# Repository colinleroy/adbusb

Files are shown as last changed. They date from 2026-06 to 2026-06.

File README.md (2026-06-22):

#  ADB to USB converter for Apple keyboards

Allow one ADB keyboard to be used on one ADB computer (old Macintosh and Apple IIgs) and one USB computer at the same time by switching between them.

Illustration

## What works

- adb passthrough between a macintosh and keyboard/mouse + softpower
- adb keyboard to usb-hid conversion:
  - iso and ansi layouts
  - locking caps lock
  - power key in usb (translated as 0x66 "keyboard power")
- tested on multiple keyboards: aek ii, m0116/m0118, appledesign...
- tested on macintosh se
  
## What don't work yet

- keyboard leds on usb: the *keyboard* library doesn't handle hid output reports
- hotplugging adb: works randomly, the microcontroller don't seems to like that
- mouse passthrough in usb-hid mode
- correct keyboard detection by the macintosh when the board is in usb mode: not a problem in practice
- collision detection handling: the program calls the keyboard at address 2

## Hardware needed

- arduino pro micro because it works on 5V and is hid capable
- a resistor (1K - 10K ohm) for the pull up
- 2 mini-din 4 pin connectors
- 2-pin switch

## How to build it

- connect the switch between A3 (PF4) and GND
- connect GND on the two mini-din pins 4
- connect 9 (PB5) to the mini-din A pin 1 (computer adb line)
- connect 8 (PB4) to the mini-din A pin 2 (computer softpower line)
- connect VCC to the mini-din B pin 3 (keyboard power)
- connect 10 (PB6) to VCC through the resistor
- connect 10 (PB6) to the mini-din B pin 1 (keyboard adb line)
- connect 16 (PB2) to the mini-din B pin 2 (keyboard softpower line)
- mark the mini-din B as the keyboard connector

> [!CAUTION]
> i don't know what happens if you invert the connectors and inject external 5V into the macintosh adb

Mini-DIN female connector front view :
```
/------\
| 4  3 |
| 2  1 |
\__==__/
```

Arduino Pro Micro pinout :
```
                                ___________
                     PD3  TXD  |    USB    |  RAW
                     PD2   20  |           |  GND        --- keyboard pin 4
                          GND  |           |  RST
computer pin 4 ---        GND  |           |  VCC        --- keyboard pin 3 ---
                     PD1    2  |           |  A3   PF4                         |
                     PD0    3  |           |  A2   PF5                         _
                     PD4    4  |           |  A1   PF6                        | |
                     PC6    5  |           |  A0   PF7               resistor | |
                     PD7    6  |           |  15   PB1                        |_|
                     PE6    7  |           |  14   PB3                         |
computer pin 2 ---   PB4    8  |           |  16   PB2   --- keyboard pin 2    |
computer pin 1 ---   PB5    9  |___________|  10   PB6   --- keyboard pin 1 ---

```

## How to compile and upload it

1. install `arduino-cli`
2. `arduino-cli core install arduino:avr`
3. `arduino-cli lib install Keyboard`
4. compile this project by `cd` in then `arduino-cli compile --fqbn arduino:avr:micro`
5. connect the board to the computer
6. get board port with `arduino-cli board list`
7. upload it `arduino-cli upload -p /dev/.......`

## References

- [Guide to the Macintosh family hardware, Chapter 8 : Apple Desktop Bus, Apple, 1990](https://archive.org/details/apple-guide-macintosh-family-hardware/page/n325/mode/2up)
- [Apple Desktop Bus Protocol, lopaciuk.eu, 2021](https://www.lopaciuk.eu/2021/03/26/apple-adb-protocol.html)
- [Understanding the ADB Service Request Signal, bigmessowires, 2016](https://www.bigmessowires.com/2016/03/30/understanding-the-adb-service-request-signal/)
- [Apple Desktop Bus (ADB), wiki.preterhuman.net](https://wiki.preterhuman.net/Apple_Desktop_Bus_(ADB))

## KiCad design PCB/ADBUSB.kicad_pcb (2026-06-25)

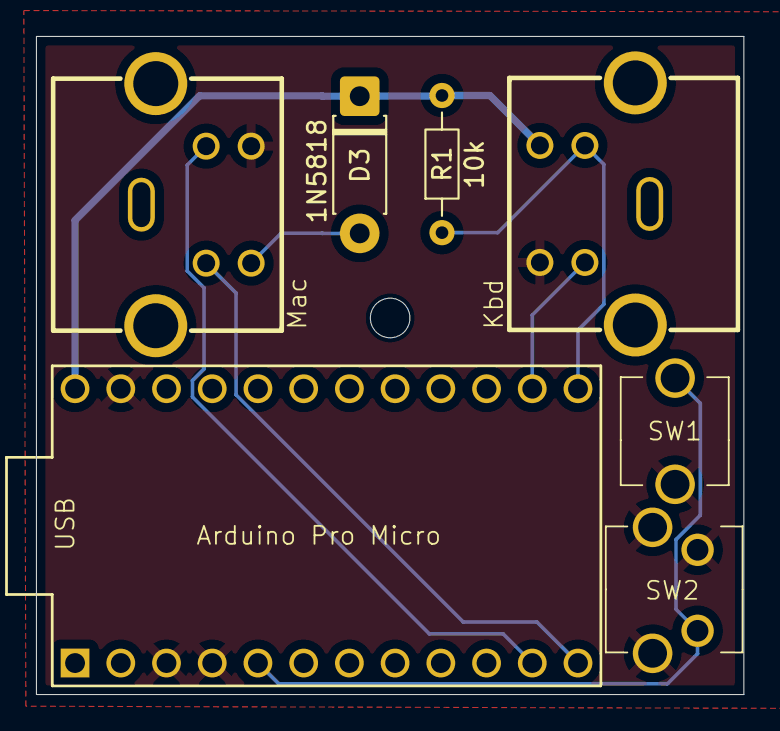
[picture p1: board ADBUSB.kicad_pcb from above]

Board: 2 copper layers, 39.3 x 36.6 mm, 7 parts (0 on the bottom side), 8 nets.

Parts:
D3: 1N5818; D_DO-41_SOD81_P7.62mm_Horizontal
J1, J2: MLD-MDC-4-02
R1: 10k; R_Axial_DIN0204_L3.6mm_D1.6mm_P7.62mm_Horizontal
SW1: SW_SPST; SPST_power_switch_horizontal
SW2: SW_SPST; SPST_power_switch
U1: ProMicro

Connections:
GND: J1.4, J2.4, SW1.2, SW2.2, SW2.3, SW2.4 (3), U1.3 (GND), U1.4 (GND), U1.23 (GND)
unnamed: D3.2 (A), J1.3
unnamed: J2.2, U1.14 (B2)
unnamed: J1.2, U1.11 (B4)
unnamed: J1.1, U1.12 (B5)
unnamed: J2.1, R1.1, U1.13 (B6)
unnamed: SW1.1, SW2.1, U1.5 (SDA)
RAW_5V: D3.1 (K), J2.3, R1.2, U1.24 (RAW)

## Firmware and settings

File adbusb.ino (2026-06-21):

#include "adb.h"
#include "conf.h"
#include "hid.h"
#include "main.h"

void setup() {
	// timer for adb timings
	TCCR1A = 0;
    TCCR1B = 0b00000010; // prescaler 8 (2 MHz)
	
	// button
	SWITCH_DDR_REGISTER  &= ~(1 << SWITCH_PIN_NUMBER); // in
	SWITCH_DDR_PORT |= (1 << SWITCH_PIN_NUMBER);  // pull-up
	
	hid_init();
    reset();  // needed only for M0116/M0118
}

void loop() {
	translation_mode();
	passthrough_mode();
}

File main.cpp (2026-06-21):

#include <Arduino.h>
#include "conf.h"
#include "main.h"
#include "adb.h"
#include "map.h"
#include "hid.h"

bool is_button_activated() {
	return !(SWITCH_PIN_REGISTER & (1 << SWITCH_PIN_NUMBER));
}

void passthrough_mode() {
    uint8_t command_byte;
    int i;
    while(is_button_activated()) {
        TCNT1 = 0;
        while(is_host_high() && TCNT1 <= 75 * 2);
        bool is_addressing_to_kb = (command_byte >> 4) == 2;
        bool is_listen = (command_byte & 0b00001100) == 0b00001000;
        bool command_complete = !is_listen || i < -2;
        if(TCNT1 >= 75 * 2 && is_addressing_to_kb && command_complete) {
            int kb_high_timeout = 185;  // max stop-to-start 260 - 75
            while(true) {
                TCNT1 = 0;
                while(is_kb_high() && TCNT1 < kb_high_timeout * 2);
                if(TCNT1 >= kb_high_timeout * 2) {
                    break;
                }
                kb_high_timeout = 75;
                set_low_host();
                while(!is_kb_high());
                set_release_host();
            }
        }
        while(is_host_high());
        set_low_kb();
        TCNT1 = 0;
        while(!is_host_high() && TCNT1 < 20000);  // timeout for button
        set_release_kb();
        int low_time = TCNT1 / 2;
        if(low_time > 700) {  // attention low
            i = 7;  // 8 bits command
            command_byte = 0;
        }
        else {
            bool bit = low_time < 50 ? 1 : 0;
            if(i >= 0) {  // if command_byte not complete 
                command_byte |= (bit << i);
            }
            i--;
            if(i == -2 && !is_kb_high()) {  // if first stop bit + keyboard SRQ
                set_low_host();
                while(!is_kb_high());
                set_release_host();
            }
        }

    }
}

void translation_mode() {
	while(!is_button_activated()) {
		key_event_t ev = transaction_get_keys();
		translate_key_press(ev.keycode_1, ev.pressed_1);
		translate_key_press(ev.keycode_2, ev.pressed_2);
        delay(11);  // like an original adb host
	}
}

void translate_key_press(uint8_t adb_code, bool is_pressed) {
	int usbcode = aek_to_hid(adb_code);
	if(usbcode) {
		if(usbcode == 0x39) {
			hid_press_key(usbcode);
			delay(100);
			hid_release_key(usbcode);
		}
		else if(is_pressed) {
			hid_press_key(usbcode);
		}
		else {
			hid_release_key(usbcode);
		}
	}
}

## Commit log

2026-06-21 initial reset for M0116
    [adbusb.ino, main.cpp]
2026-06-24 Add PCB
    [ADBUSB.kicad_pcb, ADBUSB.kicad_sch]
2026-06-25 Add a second button footprint
    So one can either use an horizontal or vertical one
    [ADBUSB.kicad_pcb, ADBUSB.kicad_sch]
